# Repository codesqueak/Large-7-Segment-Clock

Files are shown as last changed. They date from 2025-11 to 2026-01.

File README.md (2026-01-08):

# Large 7 Segment 24 Hour LED Clock

A pure logic, 7 segment 24 hour clock using large 7 segment displays

Circuit Layout

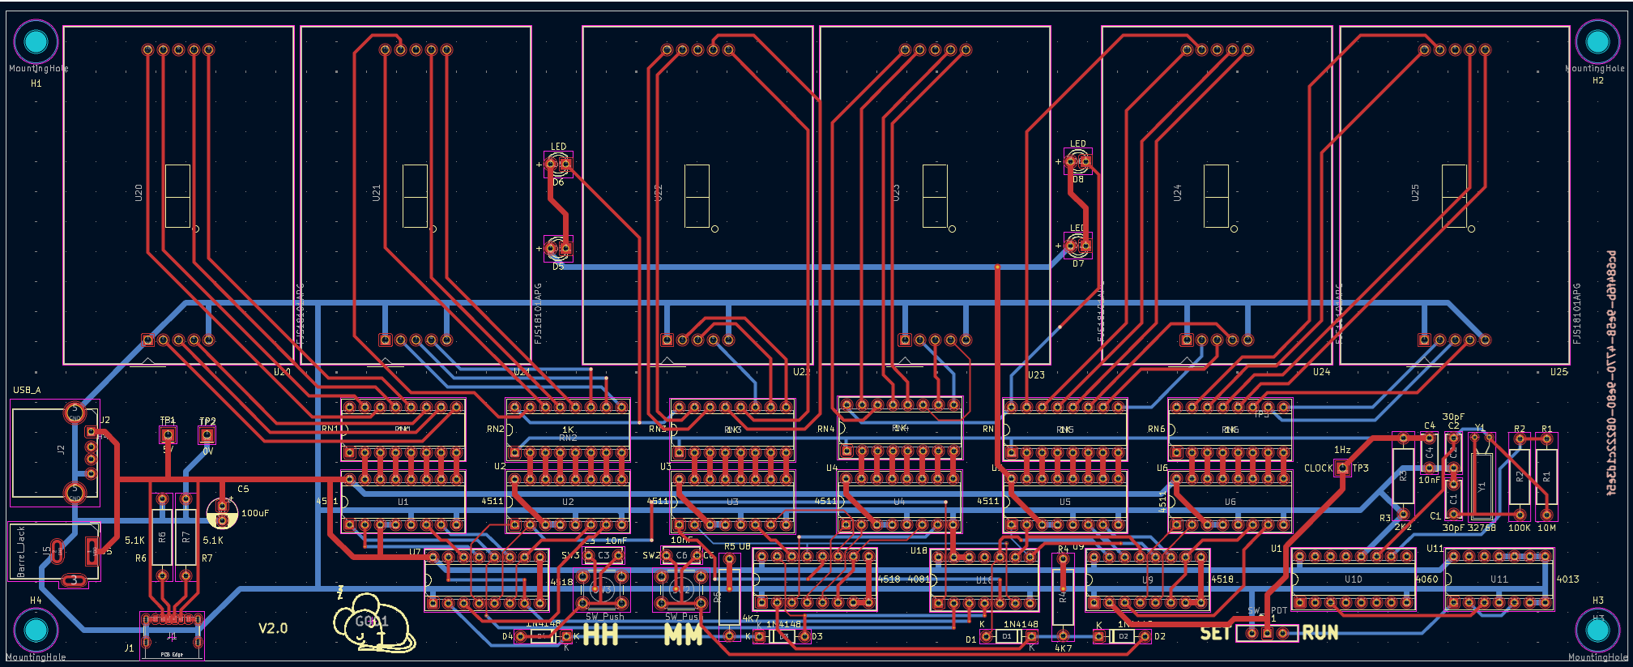
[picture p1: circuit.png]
PCB Circuit Layout


Front of PCB



Green Display



Various Colours

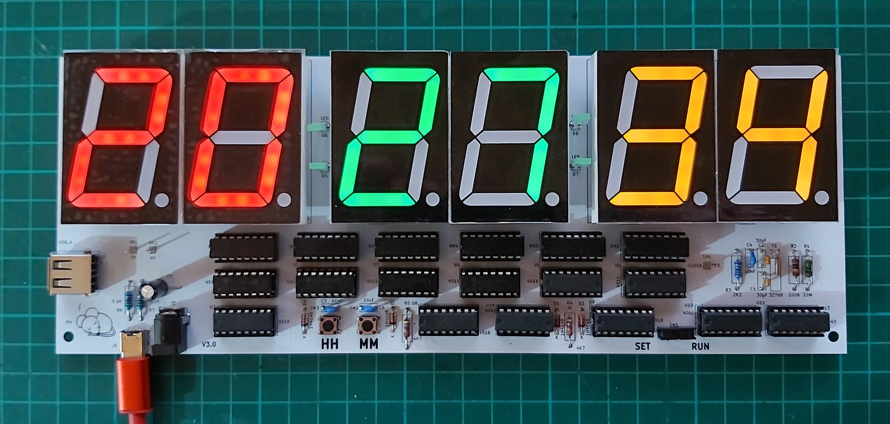
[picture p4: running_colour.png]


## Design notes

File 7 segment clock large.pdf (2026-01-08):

7 Segment Clock - Large

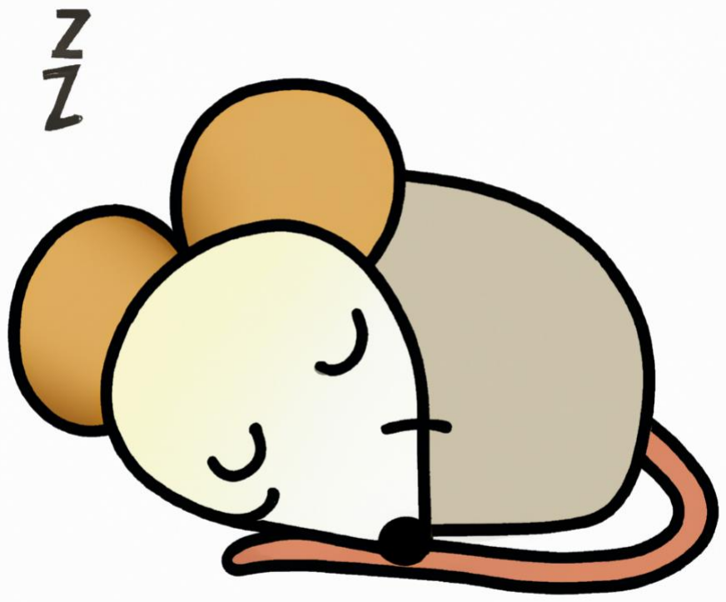
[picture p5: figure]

Issue 3.1 | Page 1 | 06-Jan-2026

## 7 Segment Clock - Large

### Instruction Manual & Functional Description

Issue 3.1 | Page 2 | 06-Jan-2026

## Contents

Issue 3.1 | Page 3 | 06-Jan-2026

## 1 Introduction

This card has been designed to generate a 24-hour clock using 7 Segment LED displays

Primary design goals:

- Simple to construct
- Parts are readily available
- No / minimal use of surface mount components
- Multiple power sources
- Full & detailed documentation

Issue 3.1 | Page 4 | 06-Jan-2026

## 2 Components

Reference | Value | Qty | Notes
C1,C2 | 30pF | 2
C3,C4,C6 | 10nF | 3 | Electrolytic
C5 | 100uF | 1
D1,D2,D3,D4 | 1N4148 | 4
D5,D6,D7,D8 | LED | 4 | Pick a colour
J1 | USB_C Receptacle Power Only 6 Pin | 1 | E.g. USB4125-GF-A – Optional for USB-C
J2 | USB_A | 1 | E.g. KUSBX-AS1N
J5 | Barrel Jack | 1 | E.g. WURTH ELEKTRONIK 694108301002
R1 | 10M | 1
R2 | 100K | 1
R3 | 2K2 | 1
R4,R5 | 4K7 | 2
R6,R7 | 5.1K | 2 | Optional for USB-C
RN1,RN2,RN3,RN4,RN5,RN6 | 1K | 6 | Resistor network, e.g.4116R-1-102
SW1 | SW_SPDT | 1
SW2,SW3 | SW_Push | 2
U1,U2,U3,U4,U5,U6 | 4511 | 6 | BCD to 7-Segment Display Driver
U7,U8,U9 | 4518 | 3 | Dual BCD Up-Counter
U10 | 4060 | 1 | 14-Stage Binary Counter
U11 | 4013 | 1 | Dual D-Type Flip-Flop
U18 | 4081 | 1 | Quad 2 Input AND Gate
U20,U21,U22,U23,U24,U25 | FJS18101APG | 6 | Large 7 segment displays – Green (Others available)
Y1 | 32768Hz | 1 | Crystal

Issue 3.1 | Page 5 | 06-Jan-2026

## 3 Construction

Read everything here before starting

### 3.1 Before you start construction

Inspect the PCB for any visible signs of damage

Select your components:

- Turned pin sockets are recommended due to robustness and reliability if you are not soldering the IC’s and displays directly to the board
- The IC’s are static sensitive. Handling precautions need to be observed
- Resistor networks have been selected for convenience but may be replaced by discrete resistors if required. Due to space considerations, these would need to be mounter partially vertically

### 3.2 Order of construction

The recommended order of construction is:

- Sockets (Or IC’s if not socketed)
- Disc capacitors / resistors / diodes
- Switches
- Power connectors
- 7 Segment Displays
- Insert IC’s (IF using sockets)
- Other items, test pins, electrolytic capacitor etc.

Issue 3.1 | Page 6 | 06-Jan-2026

## 4 Functionality

The high-level design is broken into several relatively simple sections:

1. Clock & 1 second ticks
2. Counters and SS / MM / HH resets
3. Display drive
4. Power

### 4.1 Clock

The clock is derived from a 32768 Hz crystal. This is divided down through U10 to give a 2Hz signal. This is then further divided in U11 to give the required 1Hz signal. This is then used to drive U9 (A BCD counter) to represent seconds

### 4.2 Counters

The HH:MM:SS counts are held in U7:U8:U9 respectively. These are cascade together to give the required counts. However, these would could to 99 and not the required values. To get the required values, the AND gates in U18 are used to generate reset pulses at values 24:60:60 respectively and to clock the next counter in the sequence, this giving our 00:00:00 to 23:59:59 sequence.

### 4.3 Display Drive

The BCD counter outputs are fed through fixed resistors (in networks) to drive the 7 Segment LED’s. These are common cathode devices.

### 4.4 Power

Power can be derived from either a USB-A, USB-C or Barrel Jack type connector. If the USB-C is not to be used, then the two resistors R6 & R7 can be omitted. These are used to indicate to an intelligent USB-C supply what is required

A capacitor (C5) is used to tidy up noisy supplies

Issue 3.1 | Page 7 | 06-Jan-2026

## 5 Usage of the Clock

When initially powered up, the counters can potentially have any values. Set the switch SW1 to SET. This stops the counters incrementing. Use switches SW2 & SW3 to set Minutes and Hours respectively. Switch SW1 to RUN to start the clock.

Issue 3.1 | Page 8 | 06-Jan-2026

## 6 Notes on Components

All the components used have been selected at time of design to be readily available via commercial component suppliers and eBay.

The 7 Segment Displays may be swapped for other colours. The specified ones are bright green. Allowance should be made to the maximum current draw any display will produce since the BCD driver outputs are limited to 25ma. Different values of resistors may need to be chosen by changing the selected resistor pack values.

Parts I have tested and worked

FJS18101APG - Green

FJS18101AH (Red)

FJS18101AY (Orange/Yellow)

White and blue versions of these devices also exist. However, they have 3 LEDs per segment and thus need more than the 5V available with this design.

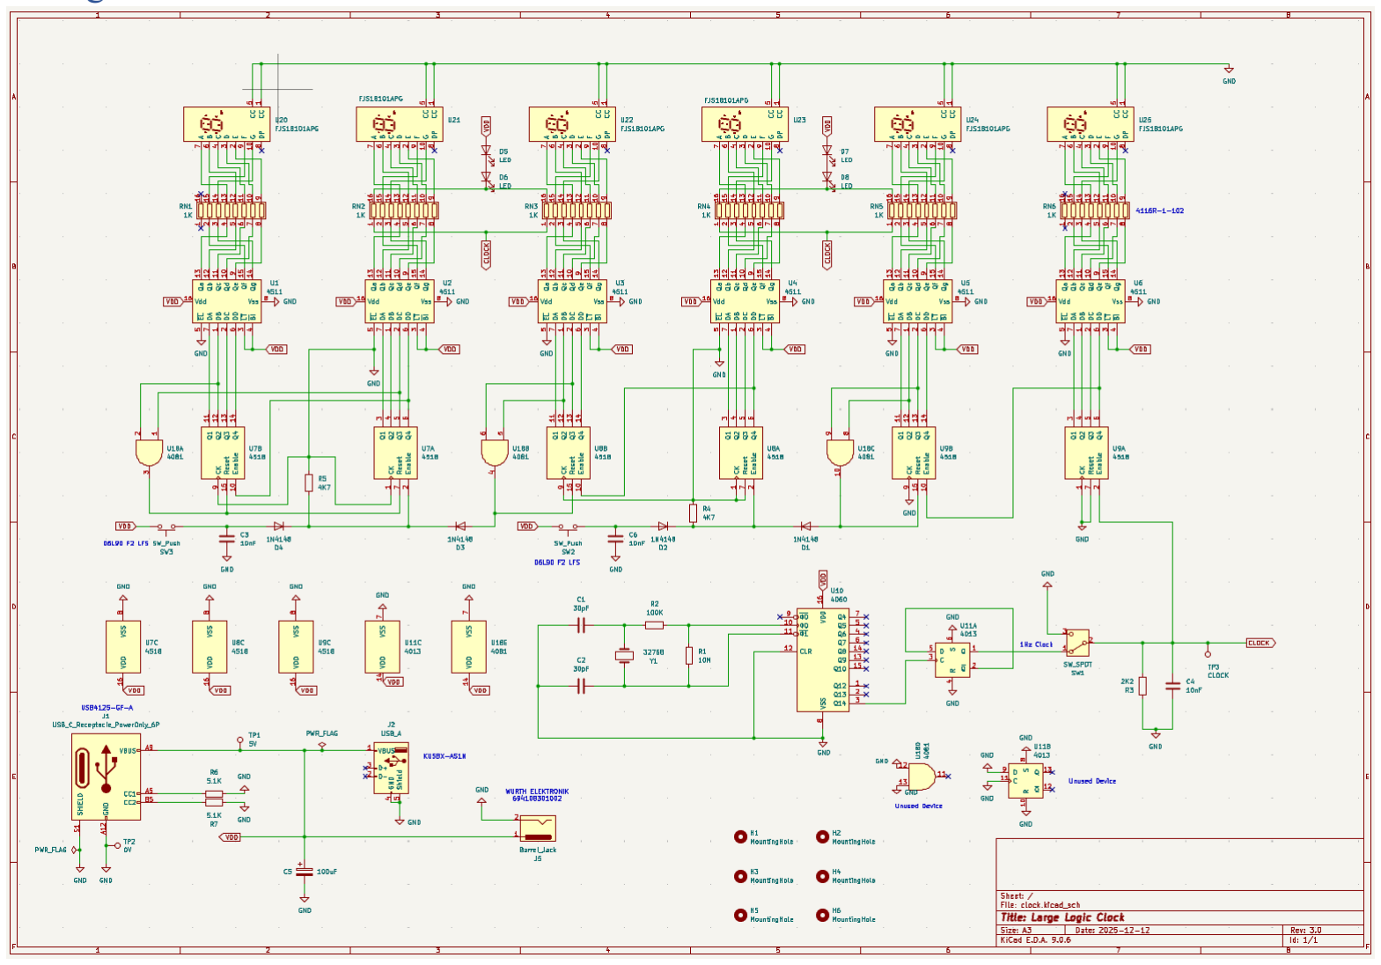
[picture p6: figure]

Issue 3.1 | Page 9 | 06-Jan-2026

## 7 Circuit Diagram

Issue 3.1 | Page 10 | 06-Jan-2026

Issue 3.1 | Page 11 | 06-Jan-2026

## 8 Errata – Changed and Fixed Items

### 8.1 Version 3.0

- Minor board shrink
- Minor re-routing
- Repositioned power connectors
- Add additional mounting holes

## 9 Reference Images

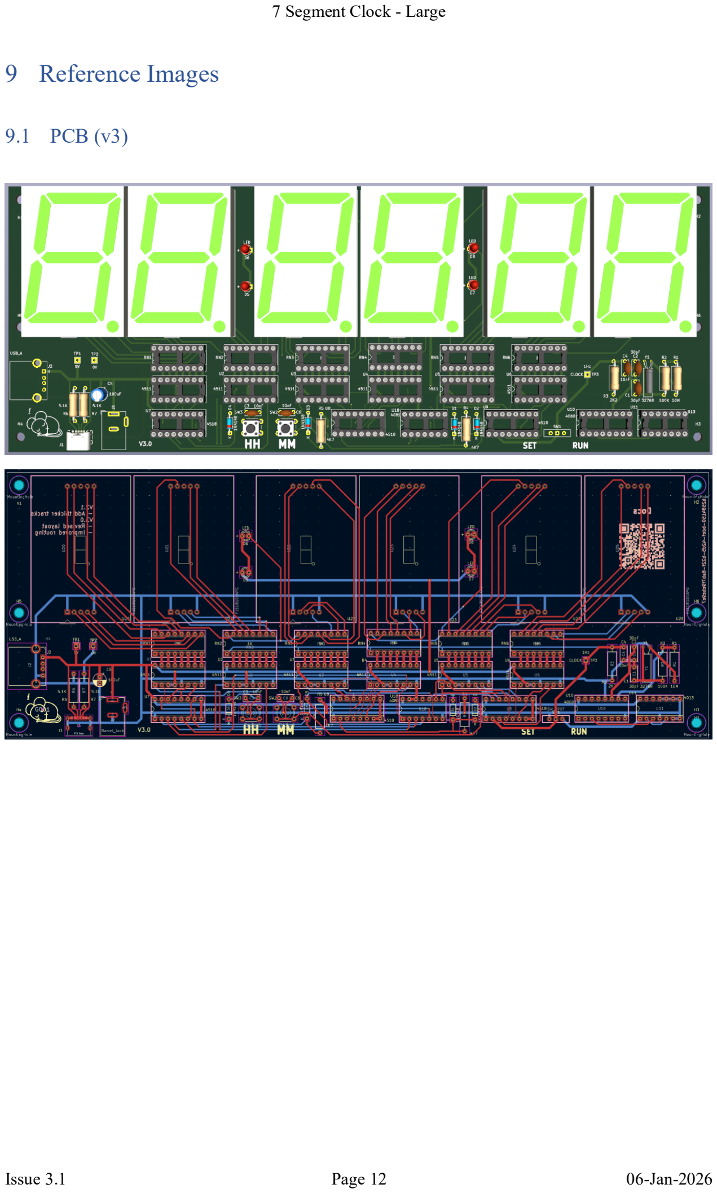
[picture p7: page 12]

Issue 3.1 | Page 12 | 06-Jan-2026

### 9.1 PCB (v3)

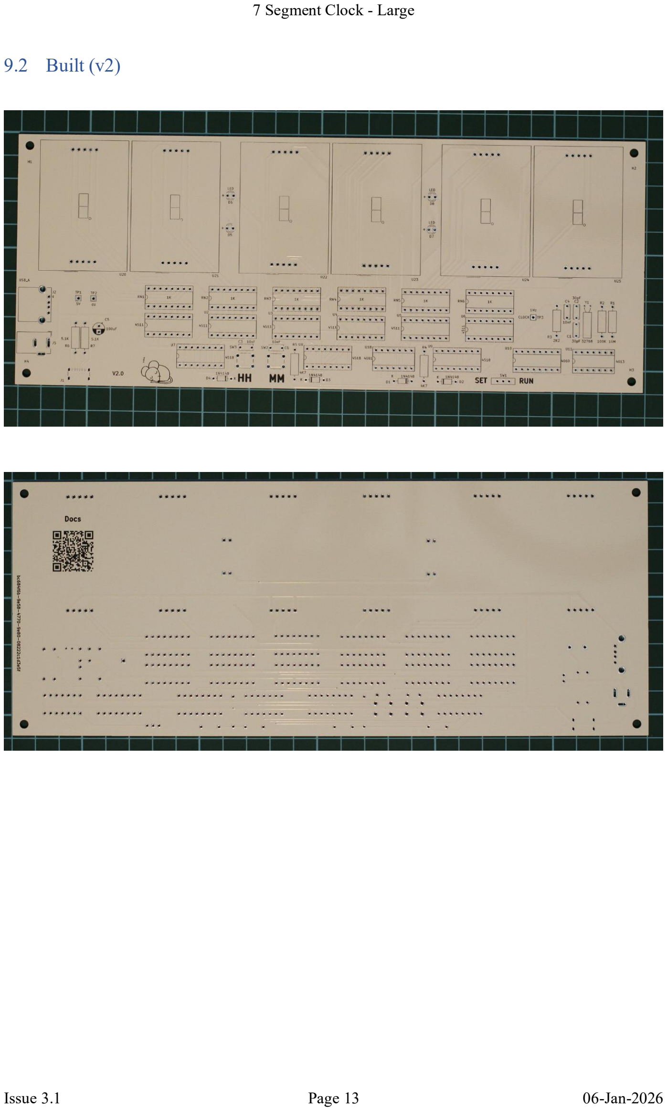
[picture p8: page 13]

Issue 3.1 | Page 13 | 06-Jan-2026

### 9.2 Built (v2)

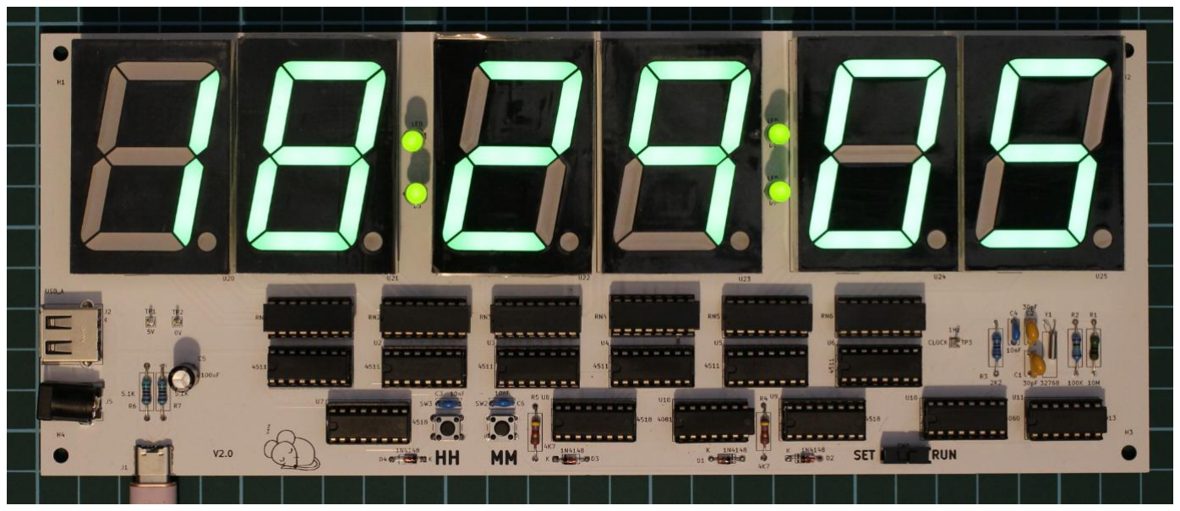
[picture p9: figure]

Issue 3.1 | Page 14 | 06-Jan-2026

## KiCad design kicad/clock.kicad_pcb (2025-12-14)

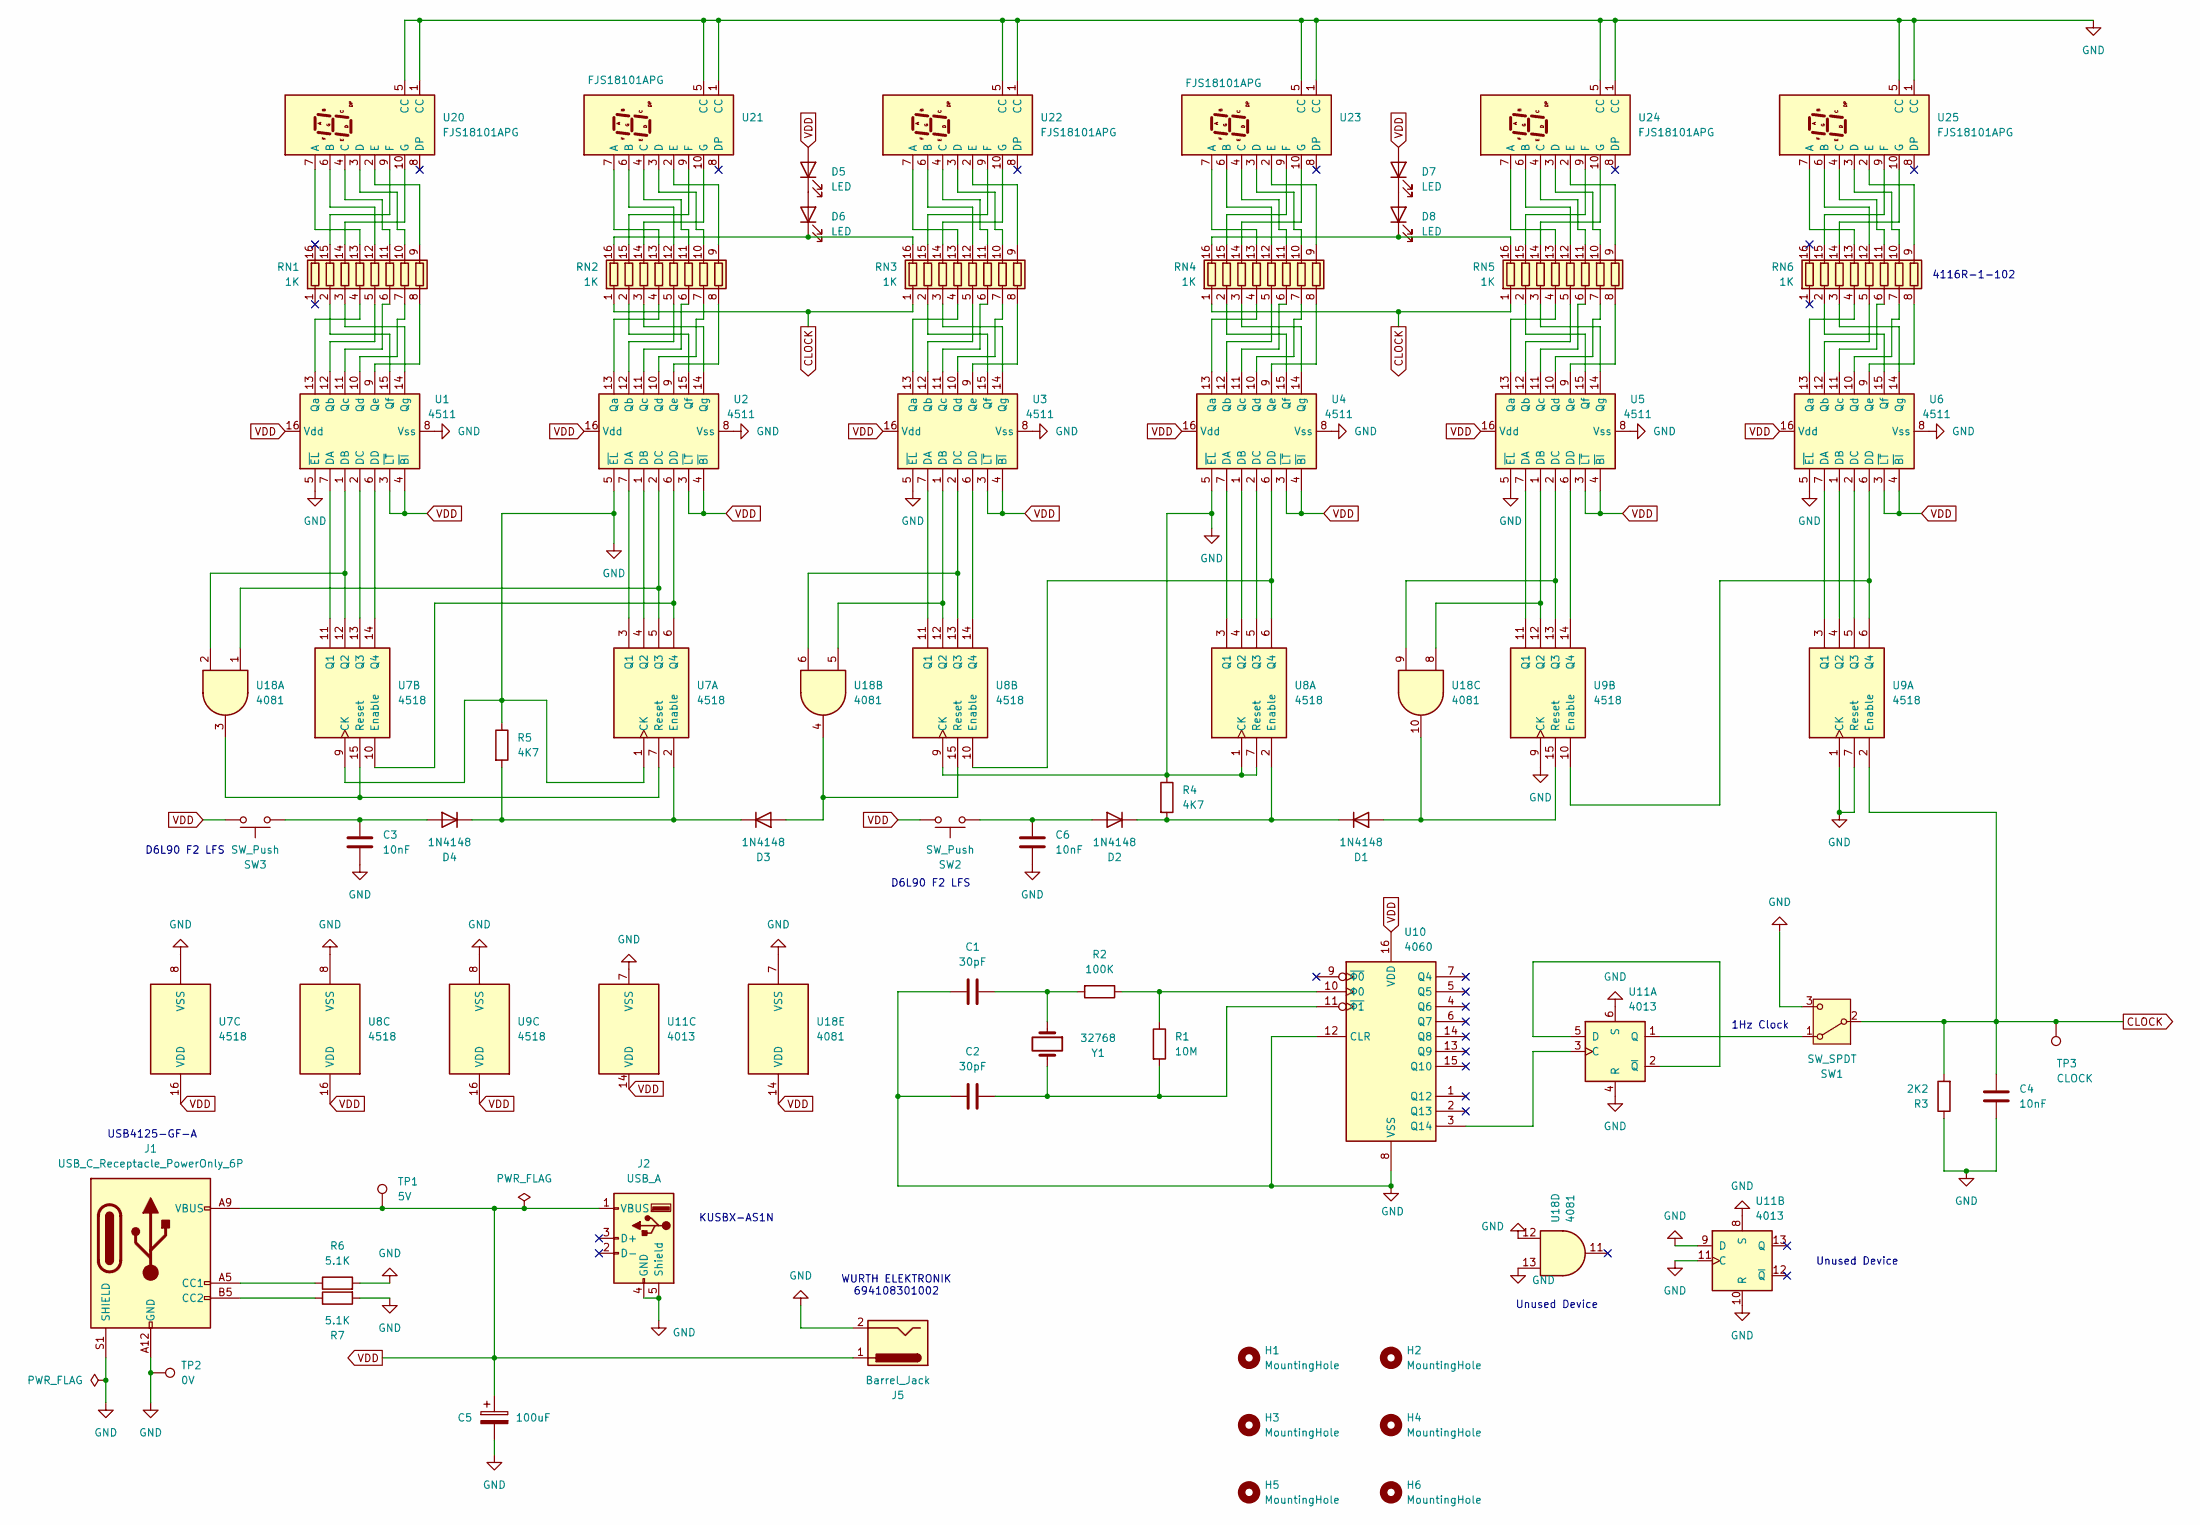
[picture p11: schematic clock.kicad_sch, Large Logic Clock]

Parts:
C1, C2: 30pF; C_Disc_D6.0mm_W2.5mm_P5.00mm
C3, C4, C6: 10nF; C_Disc_D6.0mm_W2.5mm_P5.00mm
C5: 100uF; CP_Radial_D5.0mm_P2.50mm
D1, D2, D3, D4: 1N4148; D_DO-35_SOD27_P7.62mm_Horizontal
D5, D6, D7, D8: LED; LED_D3.0mm
H1, H2, H3, H4, H5, H6: MountingHole; MountingHole_3.5mm
J1: USB_C_Receptacle_PowerOnly_6P; USB_C_Receptacle_GCT_USB4125-xx-x-0190_6P_TopMnt_Horizontal
J2: USB_A; USB_A_Kycon_KUSBX-AS1N-B_Horizontal
J5: Barrel_Jack; BarrelJack_Wuerth_6941xx301002
R1: 10M; R_Axial_DIN0309_L9.0mm_D3.2mm_P12.70mm_Horizontal
R2: 100K; R_Axial_DIN0309_L9.0mm_D3.2mm_P12.70mm_Horizontal
R3: 2K2; R_Axial_DIN0309_L9.0mm_D3.2mm_P12.70mm_Horizontal
R4, R5: 4K7; R_Axial_DIN0309_L9.0mm_D3.2mm_P12.70mm_Horizontal
R6, R7: 5.1K; R_Axial_DIN0309_L9.0mm_D3.2mm_P12.70mm_Horizontal
RN1, RN2, RN3, RN4, RN5, RN6: 1K; DIP-16_W7.62mm_Socket
SW1: SW_SPDT; SW_Slide-03_Pin-2-Common_10x2.5x6.4_P2.54mm
SW2, SW3: SW_Push; SW_PUSH_6mm_H5mm
TP1: 5V; TestPoint_THTPad_2.0x2.0mm_Drill1.0mm
TP2: 0V; TestPoint_THTPad_2.0x2.0mm_Drill1.0mm
TP3: CLOCK; TestPoint_THTPad_2.0x2.0mm_Drill1.0mm
U1, U2, U3, U4, U5, U6: 4511; DIP-16_W7.62mm_Socket
U7, U8, U9: 4518; DIP-16_W7.62mm_Socket
U10: 4060; DIP-16_W7.62mm_Socket
U11: 4013; DIP-14_W7.62mm_Socket
U18: 4081; DIP-14_W7.62mm_Socket
U20, U21, U22, U23, U24, U25: FJS18101APG
Y1: 32768; Crystal_AT310_D3.0mm_L10.0mm_Horizontal

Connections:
CLOCK: C4.1, R3.2, RN2.1 (R1.1), RN3.1 (R1.1), RN4.1 (R1.1), RN5.1 (R1.1), SW1.2 (B), TP3.1, U9.2 (Enable)
GND: C1.1, C2.1, C3.2, C4.2, C5.2, C6.2, J1.A12 (GND), J1.B12 (GND), J1.S1 (SHIELD), J2.4 (GND), J2.5 (Shield), J5.2, R3.1, R4.1, R5.1, R6.2, R7.2, SW1.3 (C), TP2.1, U1.5 (~EL), U1.8 (Vss), U2.5 (~EL), U2.8 (Vss), U3.5 (~EL), U3.8 (Vss), U4.5 (~EL), U4.8 (Vss), U5.5 (~EL), U5.8 (Vss), U6.5 (~EL), U6.8 (Vss), U7.1 (CK), U7.8 (VSS), U7.9 (CK), U8.1 (CK), U8.7 (Reset), U8.8 (VSS), U8.9 (CK), U9.1 (CK), U9.7 (Reset), U9.8 (VSS), U9.9 (CK), U10.8 (VSS), U10.12 (CLR), U11.4 (R), U11.6 (S), U11.7 (VSS), U11.8 (S), U11.9 (D), U11.10 (R), U11.11 (C), U18.7 (VSS), U18.12, U18.13, U20.1 (CC), U20.5 (CC), U21.1 (CC), U21.5 (CC), U22.1 (CC), U22.5 (CC), U23.1 (CC), U23.5 (CC), U24.1 (CC), U24.5 (CC), U25.1 (CC), U25.5 (CC)
unnamed: C1.2, R2.2, Y1.1
unnamed: D1.2 (A), U9.15 (Reset), U18.10
unnamed: D1.1 (K), D2.1 (K), R4.2, U8.2 (Enable)
unnamed: C6.1, D2.2 (A), SW2.2
unnamed: D3.2 (A), U8.15 (Reset), U18.4
unnamed: D3.1 (K), D4.1 (K), R5.2, U7.2 (Enable)
unnamed: C3.1, D4.2 (A), SW3.2
unnamed: D5.1 (K), D6.2 (A)
unnamed: D6.1 (K), RN2.16 (R1.2), RN3.16 (R1.2)
unnamed: D7.1 (K), D8.2 (A)
unnamed: D8.1 (K), RN4.16 (R1.2), RN5.16 (R1.2)
unnamed: J1.A5 (CC1), R6.1
unnamed: J1.B5 (CC2), R7.1
unnamed: RN1.2 (R2.1), U1.15 (Qf)
unnamed: RN1.15 (R2.2), U20.9 (F)
unnamed: RN1.3 (R3.1), U1.14 (Qg)
unnamed: RN1.14 (R3.2), U20.10 (G)
unnamed: RN1.4 (R4.1), U1.13 (Qa)
unnamed: RN1.13 (R4.2), U20.7 (A)
unnamed: RN1.5 (R5.1), U1.12 (Qb)
unnamed: RN1.12 (R5.2), U20.6 (B)
unnamed: RN1.6 (R6.1), U1.11 (Qc)
unnamed: RN1.11 (R6.2), U20.4 (C)
unnamed: RN1.7 (R7.1), U1.10 (Qd)
unnamed: RN1.10 (R7.2), U20.3 (D)
unnamed: RN1.8 (R8.1), U1.9 (Qe)
unnamed: RN1.9 (R8.2), U20.2 (E)
unnamed: RN2.2 (R2.1), U2.15 (Qf)
unnamed: RN2.15 (R2.2), U21.9 (F)
unnamed: RN2.3 (R3.1), U2.14 (Qg)
unnamed: RN2.14 (R3.2), U21.10 (G)
unnamed: RN2.4 (R4.1), U2.13 (Qa)
unnamed: RN2.13 (R4.2), U21.7 (A)
unnamed: RN2.5 (R5.1), U2.12 (Qb)
unnamed: RN2.12 (R5.2), U21.6 (B)
unnamed: RN2.6 (R6.1), U2.11 (Qc)
unnamed: RN2.11 (R6.2), U21.4 (C)
unnamed: RN2.7 (R7.1), U2.10 (Qd)
unnamed: RN2.10 (R7.2), U21.3 (D)
unnamed: RN2.8 (R8.1), U2.9 (Qe)
unnamed: RN2.9 (R8.2), U21.2 (E)
unnamed: RN3.2 (R2.1), U3.15 (Qf)
unnamed: RN3.15 (R2.2), U22.9 (F)
unnamed: RN3.3 (R3.1), U3.14 (Qg)
unnamed: RN3.14 (R3.2), U22.10 (G)
unnamed: RN3.4 (R4.1), U3.13 (Qa)
unnamed: RN3.13 (R4.2), U22.7 (A)
unnamed: RN3.5 (R5.1), U3.12 (Qb)
unnamed: RN3.12 (R5.2), U22.6 (B)
unnamed: RN3.6 (R6.1), U3.11 (Qc)
unnamed: RN3.11 (R6.2), U22.4 (C)
unnamed: RN3.7 (R7.1), U3.10 (Qd)
unnamed: RN3.10 (R7.2), U22.3 (D)
unnamed: RN3.8 (R8.1), U3.9 (Qe)
unnamed: RN3.9 (R8.2), U22.2 (E)
unnamed: RN4.2 (R2.1), U4.15 (Qf)
unnamed: RN4.15 (R2.2), U23.9 (F)
unnamed: RN4.3 (R3.1), U4.14 (Qg)
unnamed: RN4.14 (R3.2), U23.10 (G)
unnamed: RN4.4 (R4.1), U4.13 (Qa)
unnamed: RN4.13 (R4.2), U23.7 (A)
unnamed: RN4.5 (R5.1), U4.12 (Qb)
unnamed: RN4.12 (R5.2), U23.6 (B)
unnamed: RN4.6 (R6.1), U4.11 (Qc)
unnamed: RN4.11 (R6.2), U23.4 (C)
unnamed: RN4.7 (R7.1), U4.10 (Qd)
unnamed: RN4.10 (R7.2), U23.3 (D)
unnamed: RN4.8 (R8.1), U4.9 (Qe)
unnamed: RN4.9 (R8.2), U23.2 (E)
unnamed: RN5.2 (R2.1), U5.15 (Qf)
unnamed: RN5.15 (R2.2), U24.9 (F)
unnamed: RN5.3 (R3.1), U5.14 (Qg)
unnamed: RN5.14 (R3.2), U24.10 (G)
unnamed: RN5.4 (R4.1), U5.13 (Qa)
unnamed: RN5.13 (R4.2), U24.7 (A)
unnamed: RN5.5 (R5.1), U5.12 (Qb)
unnamed: RN5.12 (R5.2), U24.6 (B)
unnamed: RN5.6 (R6.1), U5.11 (Qc)
unnamed: RN5.11 (R6.2), U24.4 (C)
unnamed: RN5.7 (R7.1), U5.10 (Qd)
unnamed: RN5.10 (R7.2), U24.3 (D)
unnamed: RN5.8 (R8.1), U5.9 (Qe)
unnamed: RN5.9 (R8.2), U24.2 (E)
unnamed: RN6.2 (R2.1), U6.15 (Qf)
unnamed: RN6.15 (R2.2), U25.9 (F)
unnamed: RN6.3 (R3.1), U6.14 (Qg)
unnamed: RN6.14 (R3.2), U25.10 (G)
unnamed: RN6.4 (R4.1), U6.13 (Qa)
unnamed: RN6.13 (R4.2), U25.7 (A)
unnamed: RN6.5 (R5.1), U6.12 (Qb)
unnamed: RN6.12 (R5.2), U25.6 (B)
unnamed: RN6.6 (R6.1), U6.11 (Qc)
unnamed: RN6.11 (R6.2), U25.4 (C)
unnamed: RN6.7 (R7.1), U6.10 (Qd)
unnamed: RN6.10 (R7.2), U25.3 (D)
unnamed: RN6.8 (R8.1), U6.9 (Qe)
unnamed: RN6.9 (R8.2), U25.2 (E)
unnamed: SW1.1 (A), U11.1 (Q)
unnamed: U1.7 (DA), U7.11 (Q1)
unnamed: U1.1 (DB), U7.12 (Q2), U18.2
unnamed: U1.2 (DC), U7.13 (Q3)
unnamed: U1.6 (DD), U7.14 (Q4)
unnamed: U2.7 (DA), U7.3 (Q1)
unnamed: U2.1 (DB), U7.4 (Q2)
unnamed: U2.2 (DC), U7.5 (Q3), U18.1
unnamed: U2.6 (DD), U7.6 (Q4), U7.10 (Enable)
unnamed: U3.7 (DA), U8.11 (Q1)
unnamed: U3.1 (DB), U8.12 (Q2), U18.5
unnamed: U3.2 (DC), U8.13 (Q3), U18.6
unnamed: U3.6 (DD), U8.14 (Q4)
unnamed: U4.7 (DA), U8.3 (Q1)
unnamed: U4.1 (DB), U8.4 (Q2)
unnamed: U4.2 (DC), U8.5 (Q3)
unnamed: U4.6 (DD), U8.6 (Q4), U8.10 (Enable)
unnamed: U5.7 (DA), U9.11 (Q1)
unnamed: U5.1 (DB), U9.12 (Q2), U18.8
unnamed: U5.2 (DC), U9.13 (Q3), U18.9
unnamed: U5.6 (DD), U9.14 (Q4)
unnamed: U6.7 (DA), U9.3 (Q1)
unnamed: U6.1 (DB), U9.4 (Q2)
unnamed: U6.2 (DC), U9.5 (Q3)
unnamed: U6.6 (DD), U9.6 (Q4), U9.10 (Enable)
unnamed: U7.7 (Reset), U7.15 (Reset), U18.3
unnamed: U10.3 (Q14), U11.3 (C)
unnamed: C2.2, R1.2, U10.11 (~Φ1), Y1.2
unnamed: R1.1, R2.1, U10.10 (Φ0)
unnamed: U11.2 (~Q), U11.5 (D)
VDD: C5.1, D5.2 (A), D7.2 (A), J1.A9 (VBUS), J1.B9 (VBUS), J2.1 (VBUS), J5.1, SW2.1, SW3.1, TP1.1, U1.3 (~LT), U1.4 (~BI), U1.16 (Vdd), U2.3 (~LT), U2.4 (~BI), U2.16 (Vdd), U3.3 (~LT), U3.4 (~BI), U3.16 (Vdd), U4.3 (~LT), U4.4 (~BI), U4.16 (Vdd), U5.3 (~LT), U5.4 (~BI), U5.16 (Vdd), U6.3 (~LT), U6.4 (~BI), U6.16 (Vdd), U7.16 (VDD), U8.16 (VDD), U9.16 (VDD), U10.16 (VDD), U11.14 (VDD), U18.14 (VDD)

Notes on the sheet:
Unused Device
USB4125-GF-A
D6L90 F2 LFS
WURTH ELEKTRONIK 694108301002
4116R-1-102
1Hz Clock
KUSBX-AS1N

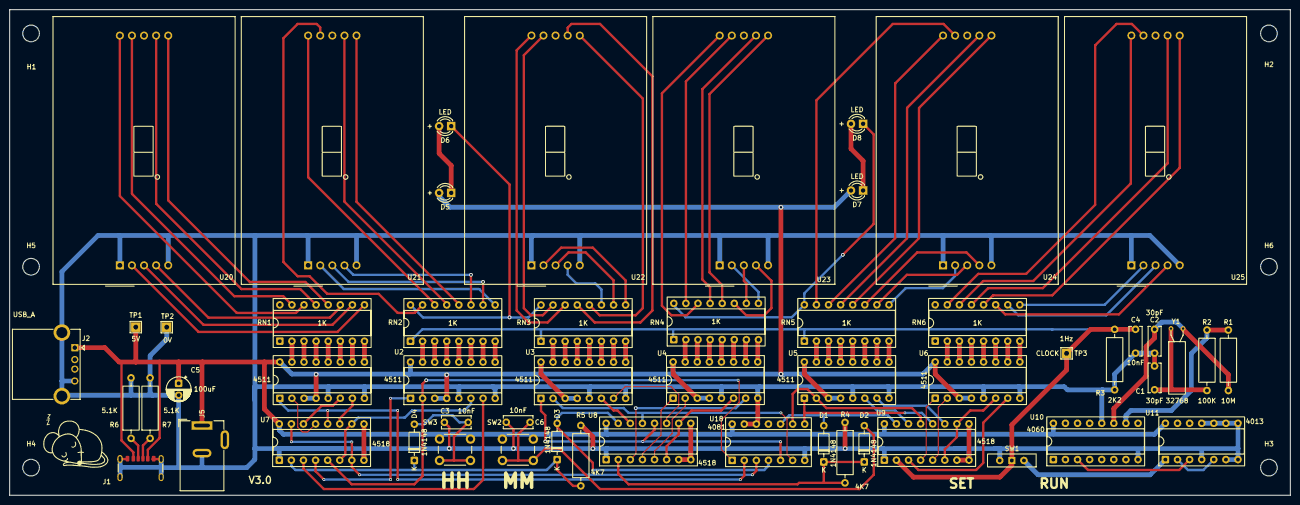
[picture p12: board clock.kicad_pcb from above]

Board: 2 copper layers, 269.0 x 102.0 mm, 62 parts (0 on the bottom side), 130 nets.

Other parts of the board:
G001: LOGO; sleepymouse_very_small

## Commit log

2025-11-25 First upload
    [clock.kicad_pcb, clock.kicad_sch]
2025-11-25 Add QR code
    [clock.kicad_pcb]
2025-12-14 Completed article
    [clock.kicad_pcb, clock.kicad_sch]
